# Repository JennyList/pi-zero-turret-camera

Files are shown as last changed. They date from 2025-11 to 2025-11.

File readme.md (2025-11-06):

# A 3 lens M12 turret camera using a Raspberry Pi Zero



This is a compact camera using a Raspberry Pi Zero and a Pimoroni Display HAT Mini. It has a 3-lens M12 turret mount.

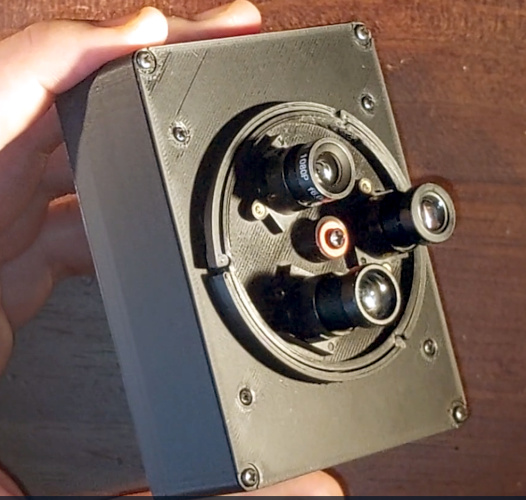
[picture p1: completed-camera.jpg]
A picture of the camera, assembled.


## You Will Need

If you want to build this from the SCAD file, you will need [my M12 turret mount library](https://github.com/JennyList/m12-turret-camera) and [my parametric project box library](https://github.com/JennyList/Jennys-rectangular-project-box).

If you merely want to print the STLs, you'll need **pi-zero-M12-camera.stl** from this repository, with **turret.stl** and **pi-zero-90-degree-module-holder.stl** from [my M12 turret mount library](https://github.com/JennyList/m12-turret-camera).

You will also need a Pi Zero with a camera module interface, [a Pimoroni Diaplay HAT Mini](https://shop.pimoroni.com/products/display-hat-mini), three M12 lens holders with lenses, and a pinhole-type Raspberry Pi camera module. This last part is not the official Raspberry Pi camera module with a PCB, instead it's the type you can find on AliExpress or similar that comes on a flexible PCB ribbon cable. The instructions for removing the pinhole lens are in the turret camera repository.

## Assembly

You'll find instructions for assembling the camera sensor and turret in [my M12 turret mount library](https://github.com/JennyList/m12-turret-camera) repository. Assemble the front of the camera, but do not attach the Raspberry Pi. You should end up witht he front assembly with the camera flexible PCB cable poking from the back of it.

The rear assembly is the "box" with a cut-out for the Pimoroni display. First screw the four stand-offs you've just 3D printed, to the upper side of the Pi, with small self-taping screws. Then fit the Display HAT Mini to the Pi. You can then fit it to the box witht he Display HAT Mini in its opening, and attach it to the box with four more small screws. Make sure the Pi connectors face towards the opening in the box.

Connect the camera cable tot he Pi, and fit the turret assembly to the box with four more small screws.

## In Use

This camera does not have a battery. It's an experimental device, you will have to power it from a USB power supply or battery pack.

**pi-snapshot-camera.py** is a Python script to run the camera. It's slow and not very good at all, I am not the world's best coder, but it works. You can either set it to run on startup, or hook up a terminal and run it by hand.

- Button X is the shutter
- Button A leaves the Python script
- Button B shuts down the Pi

Focusing has to be done with care, particularly on the longer lenses. You may need to remove the IR filter in your M12 lens holder to give enough focusing space.

## Video description

Click the image to be taken to my YouTube video on this camera.

IMAGE ALT TEXT HERE (https://www.youtube.com/watch?v=UntZmKj_IJE)

## Credits

Jenny List 2025
CC-BY-SA 4.0

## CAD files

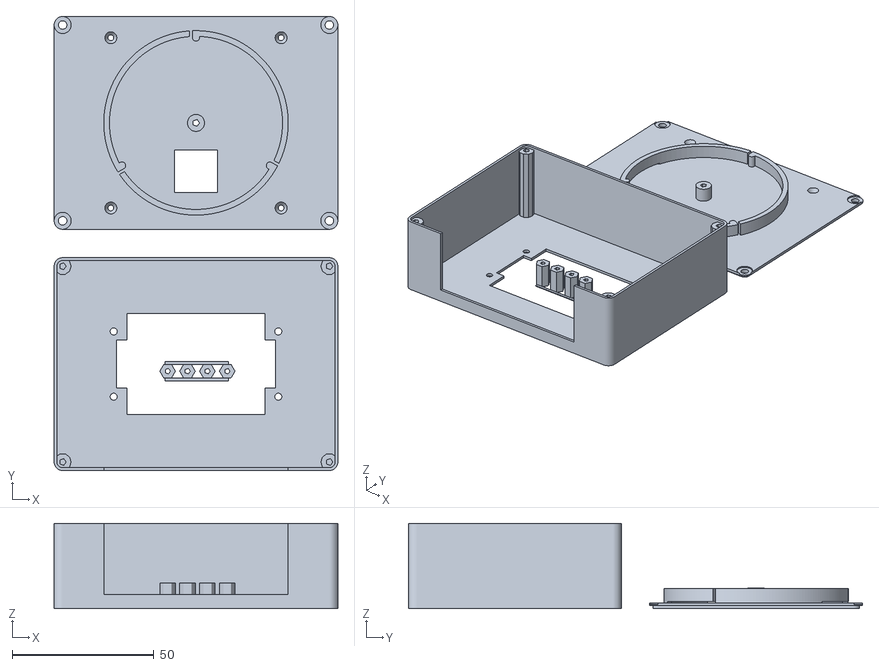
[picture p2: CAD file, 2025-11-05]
pi-zero-M12-camera.stl
100.0 x 160.0 x 30.0

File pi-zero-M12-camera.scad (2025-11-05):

/*

A handheld camera case with a turret mount, for Raspberry Pi Zero
Jenny List 2025
CC-BY-SA 4.0

*/

// Requirws thw following two libraries
include <./jennys-rectangular-project-box.scad>
include <./m12-turret-camera.scad>

//Main box with camera mount
module zeroCameraBox(){
    difference(){
        projectBox(100,75,30,3,1,1.25); //the box itself    
        translate([50,37.5,0]){ //cut-outs for Zero mounting holes
            translate([-29,-11.5,0]) cylinder(5,1.25,1.25,$fn=90);
            translate([29,-11.5,0]) cylinder(5,1.25,1.25,$fn=90);
            translate([-29,11.5,0]) cylinder(5,1.25,1.25,$fn=90);
            translate([29,11.5,0]) cylinder(5,1.25,1.25,$fn=90);
        }
        translate([50,0,20]){ 
            cube([65,5,30],true); //cut-out for cables
        }
        translate([50,37.5,0]) cube([48.5,35.5,5],true); //cut-out for Pimoroni screen
        translate([50,37.5,0]) cube([56,17,5],true); //cut-out for Pimoroni buttons
    }
}
//Lid for box with Pimoroni sreeen and Zero mount
module zeroCameraLid(){
    difference(){
        projectBoxLid(100,75,30,3,1,1.25);
        translate([15,2.5,0]){ 
            cube([70,70,70]); //cut-out for turret assembly
        }
    }
    translate([50,37.5,2]) rotate([180,0,0]) TurretHolder();
}

//Four stand-offs for between the Pimoroni board and the Pi
module zeroCameraStandoffs(){
    for(i=[0:3]){
        translate([i*7,0,0]){
            difference(){
                cylinder(9,2.75,2.75,$fn=6);
                cylinder(9,1,1);
            }
        }
    }
    translate([-1,2.38,0]) cube([22.5,1,0.25]); //printing supports
    translate([-1,-3.38,0]) cube([22.5,1,0.25]);
}

//Main box with Pi and Pimoroni screen mounting.
zeroCameraBox();
//Lid with turret mount
translate([0,160,2]) rotate([180,0,0]) zeroCameraLid();
//Four stand-offs for mounting the Raspberry Pi Zero
translate([40,35,0]) zeroCameraStandoffs();

//You will also need the turret itself and the camera back plate.
//These can be found in m12-turret-camera.scad

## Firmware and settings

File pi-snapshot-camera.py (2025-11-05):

#!/usr/bin/env python3

#
# World's worst Raspberry Pi camera script
# Jenny List, January 2023
#
# For a Pi Zero with a camera module and a Pimoroni Display HAT Mini.
#
# It's horribly inefficient, there's no pretence of optimisation, you could certainly do better than this.
#

from picamera2 import Picamera2, Preview
import time
from displayhatmini import DisplayHATMini
from libcamera import controls
from PIL import Image
import os
from os.path import exists
import ST7789 as ST7789

# set up parameters for display library
disp = ST7789.ST7789(
    height=240,
    width=320,
    rotation=180,
    port=0,
    cs=1,
    dc=9,
    backlight=13,
    spi_speed_hz=60 * 1000 * 1000,
    offset_left=0,
    offset_top=0
)
disp.begin()

# Set up display hat
width = DisplayHATMini.WIDTH
height = DisplayHATMini.HEIGHT
buffer = Image.new("RGB", (width, height))
displayhatmini = DisplayHATMini(buffer)

# Find most recent file name
i = 0
while exists("./Pictures/test" + str(i) + ".jpg"):
    i += 1

# Set up camera
picam2 = Picamera2()
preview_config = picam2.create_preview_configuration()
capture_config = picam2.create_still_configuration()
picam2.configure(preview_config)
picam2.start()
# Following line for cameras with autofocus only.
# picam2.set_controls({"AfMode": controls.AfModeEnum.Continuous})

# Main loop
while True:
    image = picam2.capture_image("main") # Display viewfinder image
    image = image.resize((width, height))
    disp.display(image)
    if displayhatmini.read_button(displayhatmini.BUTTON_X): # Detect shutter press
        picam2.switch_mode(capture_config)
        picam2.capture_file("./Pictures/test" + str(i) + ".jpg") # Capture in hi res mode
        picam2.switch_mode(preview_config)
        displayhatmini.set_led(0.1, 0.1, 0.1) # Flash the LED white
        time.sleep (0.02)
        displayhatmini.set_led(0, 0, 0)
        i += 1
    if displayhatmini.read_button(displayhatmini.BUTTON_A): # Detect leave script button
        displayhatmini.set_led(0, 0.1, 0) # Flash the LED green
        time.sleep (0.02)
        displayhatmini.set_led(0, 0, 0)
        break
    if displayhatmini.read_button(displayhatmini.BUTTON_B): # Detect shutdown button
        displayhatmini.set_led(0.1, 0, 0) # Flash the LED red
        time.sleep (0.02)
        os.system ('sudo shutdown -h now')
        displayhatmini.set_led(0, 0, 0)
